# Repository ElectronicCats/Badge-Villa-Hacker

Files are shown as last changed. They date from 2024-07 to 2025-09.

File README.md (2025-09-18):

# La Villa Hacker 2025 Badge

## Technology

- CH32V003
- NRF24L01
- Display OLED
- 2x AAA Battery Holder
- Shitty Addon Connector

## Getting Started

Your badge comes with a pre-installed firmware, but in case you need to reprogram it, you can use the binaries from the release section.

If you want to build your own firmware, check out the [README](firmware/README.md) in the firmware folder.

## Gratitude
Do you want to say thank you? Tag these companies on social networks and show them your badge, thanks to them it is possible

- [Electronic Cats](https://electroniccats.com/)

## License

Electronic Cats invests time and resources providing this open source design, please support Electronic Cats and open-source hardware by purchasing products from Electronic Cats!

Designed by Electronic Cats.

Hardware released under an CERN Open Hardware Licence v1.2. See the LICENSE_HARDWARE file for more information.

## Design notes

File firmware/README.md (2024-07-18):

## Characteristics

* Microcontroller Puya PY32F002A    
  * PY32F002Ax5(20KB Flash/3KB RAM) SPI, USART, I2C, ADC.

## License
<a>
  
</a>

Designed by Electronic Cats for HackGDL

Electronic Cats invests time and resources in providing this open-source design. Please support Electronic Cats and open-source hardware by purchasing products from Electronic Cats!

Hardware released under ...

# PY32F0 SDK reference for Windows

[How to install the SDK for windows](https://github.com/ElectronicCats/puya-projects)

* Puya PY32F0 seriees template project for GNU Arm Embedded Toolchain
* Supported programmers: J-Link
* Supported IDE: VSCode

# File Structure

```
├── Build                       # Build results
├── Docs                        # Datesheets and User Manuals
├── Examples
│   ├── FreeRTOS                # FreeRTOS examples
│   ├── HAL                     # HAL library examples
│   └── LL                      # LL(Low Layer) library examples
├── Libraries
│   ├── BSP                     # SysTick delay and printf for debug
│   ├── BSP_LL                  # SysTick delay and printf for debug
│   ├── CMSIS
│   ├── FreeRTOS                # FreeRTOS library
│   ├── LDScripts               # LD files
│   ├── PY32F0xx_HAL_Driver     # MCU peripheral driver
│   └── PY32F0xx_LL_Driver      # MCU low layer peripheral driver
├── Makefile                    # Make config
├── Misc
│   ├── Flash
│   │   ├── JLinkDevices        # JLink flash loaders
│   │   └── Sources             # Flash algorithm source code
│   ├── Puya.PY32F0xx_DFP.x.pack # DFP pack file for PyOCD
│   └── SVD                     # SVD files
├── README.md
├── rules.mk                    # Pre-defined rules include in Makefile 
└── User                        # User application code
```

# Requirements

* Programmer
  * J-Link: J-Link OB programmer: https://linhkienthuduc.com/jlink-ob-072-mach-nap-cho-arm-cortex-m
* SEGGER J-Link Software and Documentation pack [https://www.segger.com/downloads/jlink/](https://www.segger.com/downloads/jlink/)
* GNU Arm Embedded Toolchain
* Make 

# Try Other Examples

[Forked Repository](https://github.com/IOsetting/py32f0-template)
More examples can be found in *Examples* folder of the forked repository, copy and replace the files under *User* folder of this repository to try different examples.

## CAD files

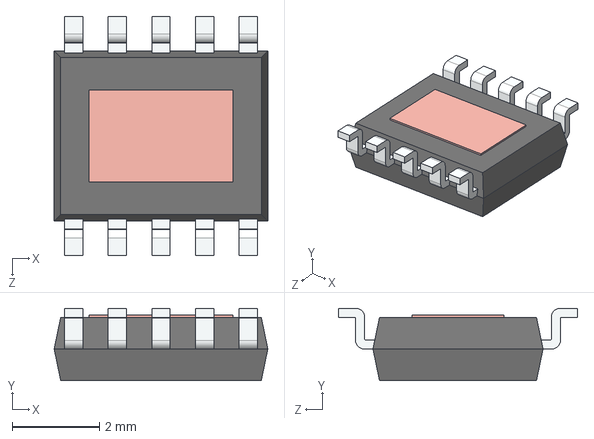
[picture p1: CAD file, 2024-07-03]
hardware/3d/ESOP-10.STEP
4.90 x 1.66 x 5.48 mm

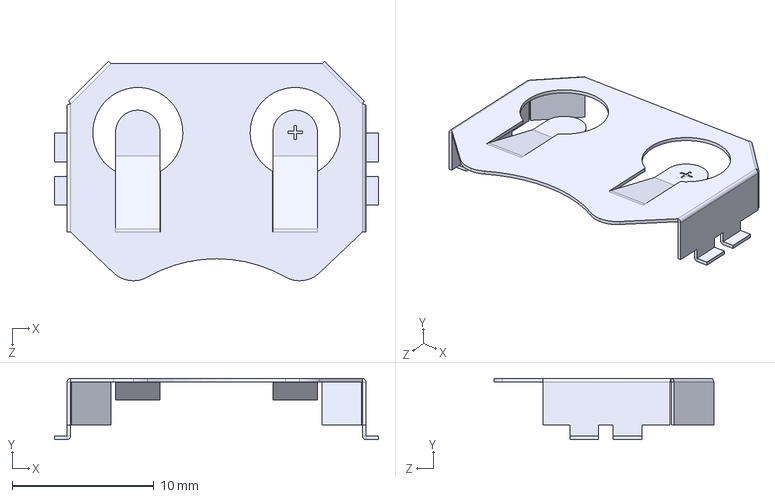
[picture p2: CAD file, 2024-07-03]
hardware/3d/BAT-HLD-001--3DModel-STEP-56544.STEP
22.9 x 4.32 x 15.5 mm

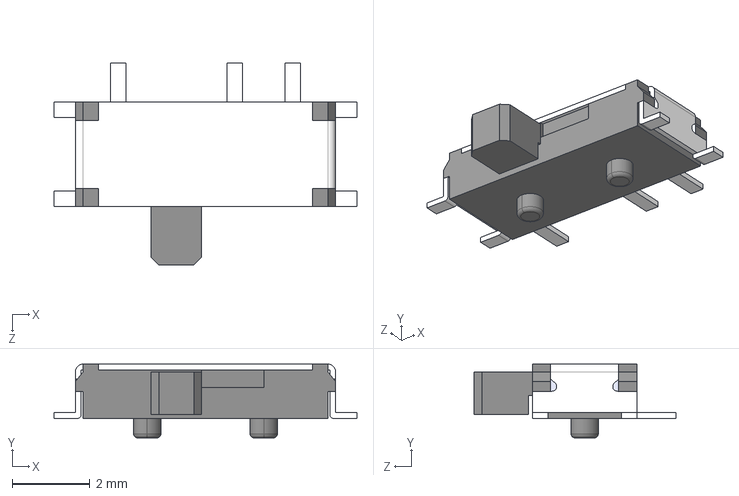
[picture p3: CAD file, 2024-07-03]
hardware/3d/MSK12C02.stp
7.80 x 1.90 x 5.20 mm

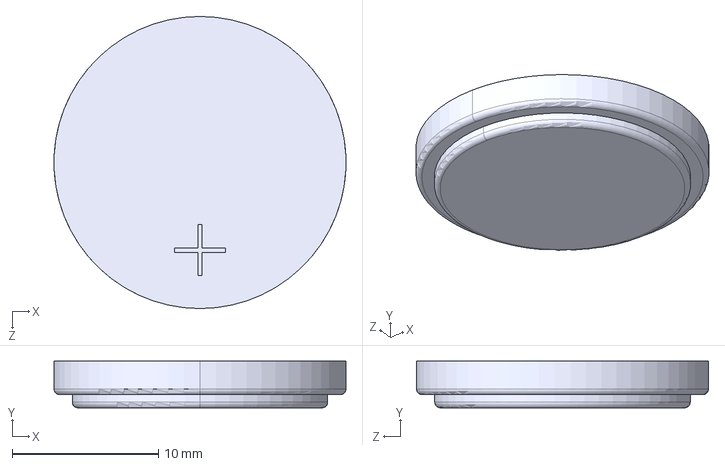
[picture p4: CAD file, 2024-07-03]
hardware/3d/CR2032--3DModel-STEP-56544.STEP
20.0 x 3.20 x 20.0 mm

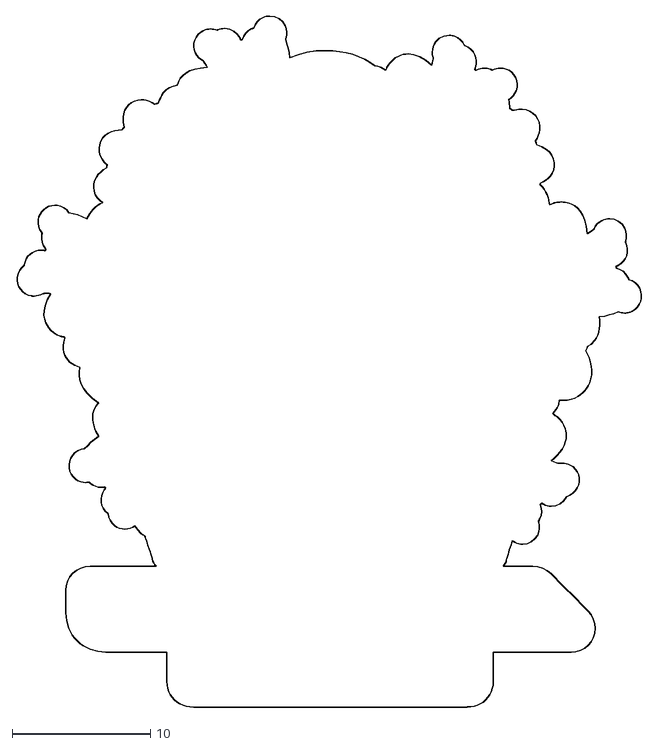
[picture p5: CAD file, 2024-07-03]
hardware/3d/Archivo SVG Badge La villa Hacker.dxf
45.4 x 50.0

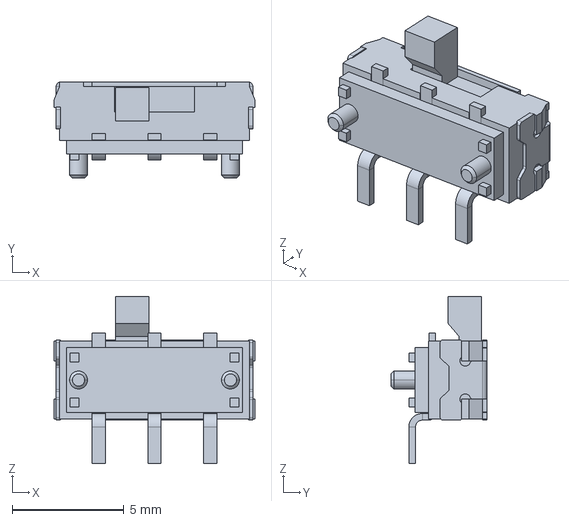
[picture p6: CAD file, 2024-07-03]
hardware/3d/JS102011SAQN--3DModel-Eagle-1.STEP
9.00 x 4.30 x 7.50 mm

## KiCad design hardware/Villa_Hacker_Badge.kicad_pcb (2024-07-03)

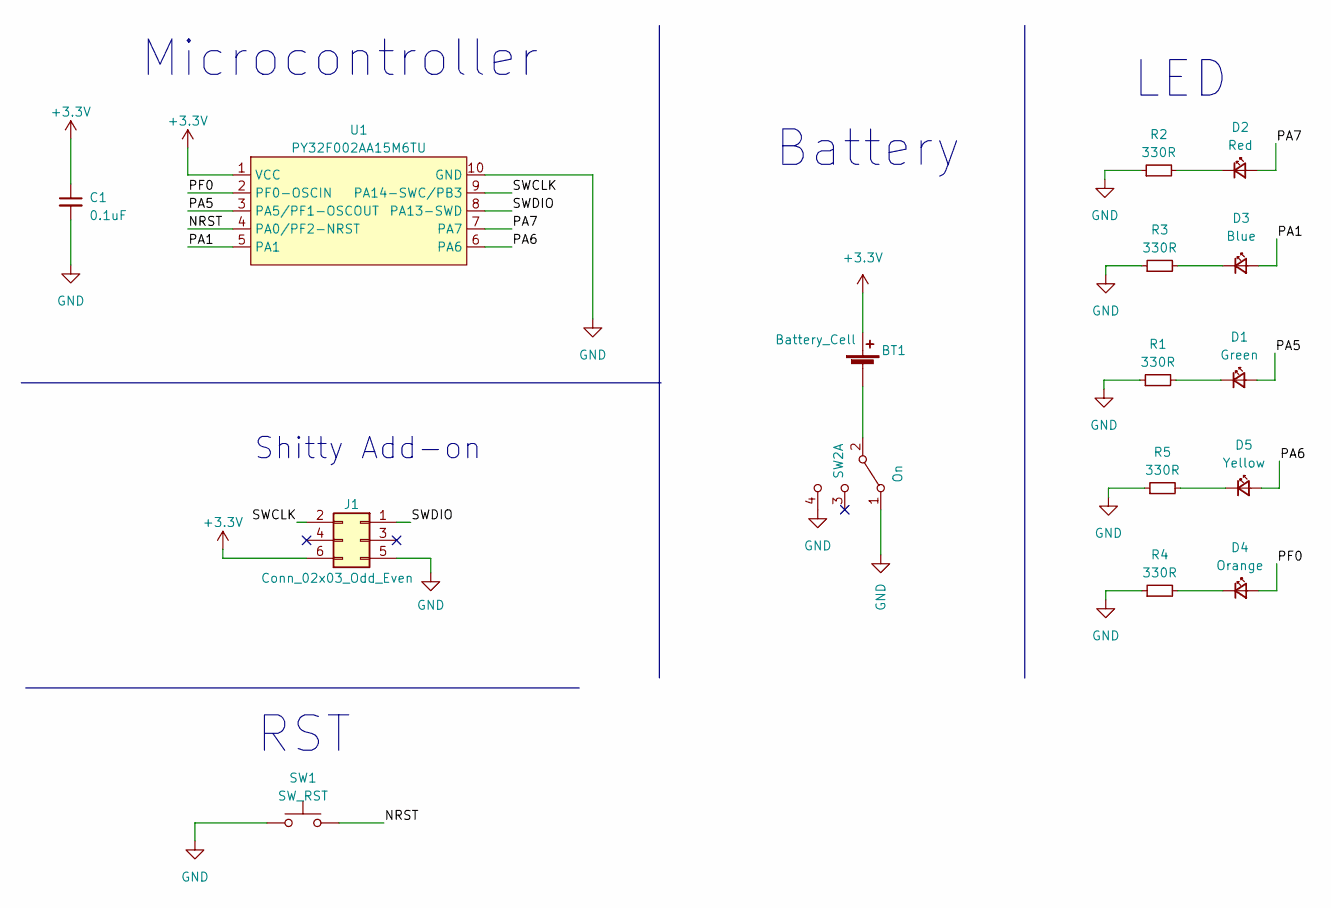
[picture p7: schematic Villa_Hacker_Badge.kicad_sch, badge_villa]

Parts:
BT1: Battery_Cell; BAT-HLD-001; LCSC# C964833
C1: 0.1uF; C_0805_2012Metric; LCSC# C235731
D1: Green; LED_0805_2012Metric; LCSC# C965815
D2: Red; LED_0805_2012Metric; LCSC# C965812
D3: Blue; LED_0805_2012Metric; LCSC# C205441
D4: Orange; LED_0805_2012Metric; LCSC# C434437
D5: Yellow; LED_0805_2012Metric; LCSC# C84261
J1: Conn_02x03_Odd_Even; PinHeader_2x03_P2.54mm_Vertical; LCSC# C706893
R1, R2, R3, R4, R5: 330R; R_0805_2012Metric; LCSC# C119075
SW1: SW_RST; SW_SPST_TL3342; LCSC# C318889
SW2: On; MSK12C02; LCSC# C431540
U1: PY32F002AA15M6TU; PY32F002AA15M; LCSC# C5292058

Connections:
+3.3V: BT1.2 (+), C1.1, J1.6, U1.1 (VCC)
/NRST: SW1.2, U1.4 (PA0/PF2-NRST)
/PA1: D3.2 (A), U1.5 (PA1)
/PA5: D1.2 (A), U1.3 (PA5/PF1-OSCOUT)
/PA6: D5.2 (A), U1.6 (PA6)
/PA7: D2.2 (A), U1.7 (PA7)
/PF0: D4.2 (A), U1.2 (PF0-OSCIN)
/SWCLK: J1.2, U1.9 (PA14-SWC/PB3)
/SWDIO: J1.1, U1.8 (PA13-SWD)
GND: C1.2, J1.5, R1.1, R2.1, R3.1, R4.1, R5.1, SW1.1, SW2.1 (A), SW2.4 (C), U1.10 (GND)
unnamed: BT1.1 (-), SW2.2 (B)
unnamed: D1.1 (K), R1.2
unnamed: D2.1 (K), R2.2
unnamed: D3.1 (K), R3.2
unnamed: D4.1 (K), R4.2
unnamed: D5.1 (K), R5.2

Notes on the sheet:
Shitty Add-on
Battery
Microcontroller
LED
RST

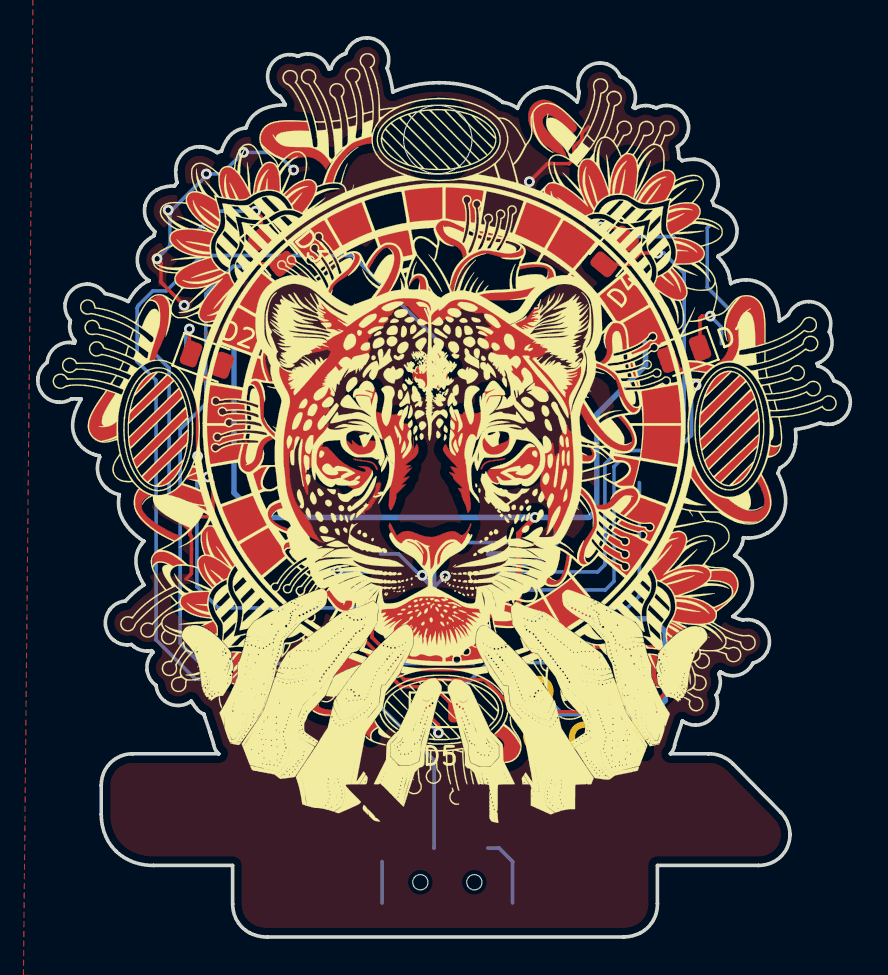
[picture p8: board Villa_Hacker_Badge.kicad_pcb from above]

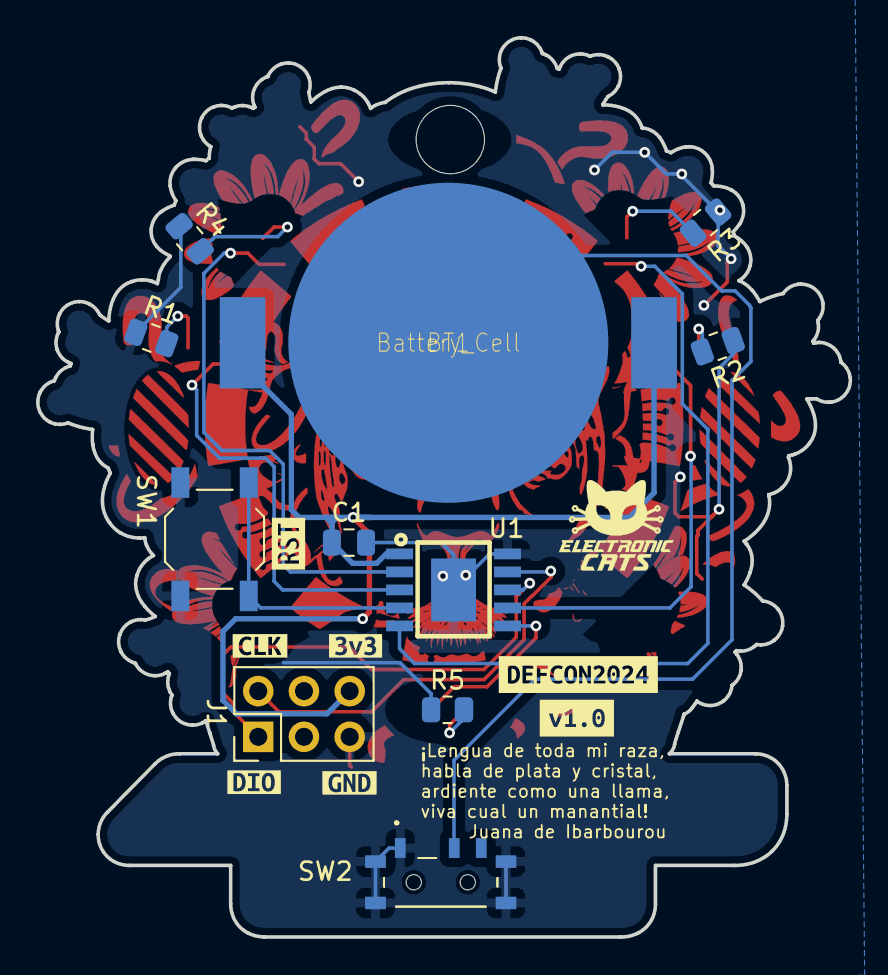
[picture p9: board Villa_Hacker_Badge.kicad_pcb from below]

Board: 2 copper layers, 45.1 x 50.0 mm, 24 parts (18 on the bottom side), 16 nets.

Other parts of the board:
Ref**: Val**; Archivo SVG Badge La villa Hacker
kibuzzard-6685D235: G***; kibuzzard-6685D235
kibuzzard-66857BF8: G***; kibuzzard-66857BF8
kibuzzard-66857C28: G***; kibuzzard-66857C28
kibuzzard-668588B5: G***; kibuzzard-668588B5
kibuzzard-6685884A: G***; kibuzzard-6685884A
kibuzzard-66858654: G***; kibuzzard-66858654
kibuzzard-66858661: G***; kibuzzard-66858661

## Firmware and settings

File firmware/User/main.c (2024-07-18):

/**
 ******************************************************************************
 * @file    main.c
 * @author  MCU Application Team
 * @brief   Main program body
 ******************************************************************************
 * @attention
 *
 * <h2><center>&copy; Copyright (c) Puya Semiconductor Co.
 * All rights reserved.</center></h2>
 *
 * <h2><center>&copy; Copyright (c) 2016 STMicroelectronics.
 * All rights reserved.</center></h2>
 *
 * This software component is licensed by ST under BSD 3-Clause license,
 * the "License"; You may not use this file except in compliance with the
 * License. You may obtain a copy of the License at:
 *                        opensource.org/licenses/BSD-3-Clause
 *
 * J-Link Connections: https://private-user-images.githubusercontent.com/44976441/277049150-2c44cddc-163c-4924-840f-2b99760bbca3.png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
 * PUYA instructions: https://github.com/ElectronicCats/puya-projects
 *
 ******************************************************************************
 */

/* Includes ------------------------------------------------------------------*/
#include "py32f0xx_bsp_printf.h"
#include <stdint.h>

/* Private define ------------------------------------------------------------*/
/* Private variables ---------------------------------------------------------*/
/* Private user code ---------------------------------------------------------*/
/* Private macro -------------------------------------------------------------*/
/* Private function prototypes -----------------------------------------------*/
static void APP_LedConfig(void);
uint16_t delay1 = 2000, delay3 = 3000, interimPeriod = 100;
uint8_t delay = 200, delay2 = 250, delay4 = 50, delay5 = 500;
uint8_t times = 0, init = 0;
uint8_t sequenceNumber = 1, timesSecretCode = 2, bitNumber = 0;

uint32_t ports[] = {GPIOA, GPIOA, GPIOF, GPIOA, GPIOA};
uint8_t pins[] = {0x0080, 0x0002, 0x0001, 0x0020, 0x0040}; 

uint8_t message[] = {"LATINO"};

void HEX2NIBBLE()
{
  uint8_t nibble1, nibble2;
  for (uint8_t i = 0; i < sizeof(message) - 1; i++)
  {
    nibble1 = message[i] & 0x0F;
    nibble2 = message[i] >> 4;
    bitNumber += 1;
    blinkBitNumber();
    setBits(nibble1);
    setBits(nibble2);
    ledsOff();
  }
}

void setBits(uint8_t nibble)
{
  uint8_t nibbleAux = nibble;
  for (uint8_t i = 0; i < 4; i++)
  {
    if (nibbleAux & 0x01) // LED ON
    {
      HAL_GPIO_OnPin(ports[i], pins[i]);
    }
    else
    {
      HAL_GPIO_OffPin(ports[i], pins[i]);
    }
    nibbleAux = nibble >> i + 1;
  }
  HAL_Delay(750);
}

void blinkBitNumber()
{
  for (uint8_t i = 0; i < 2; i++)
  {
    HAL_GPIO_OnPin(GPIOA, GPIO_PIN_6);
    HAL_Delay(delay);
    HAL_GPIO_OffPin(GPIOA, GPIO_PIN_6);
    HAL_Delay(delay);
  }
}

void ledsOff()
{
  HAL_GPIO_OffPin(GPIOF, GPIO_PIN_0);
  HAL_GPIO_OffPin(GPIOA, GPIO_PIN_1);
  HAL_GPIO_OffPin(GPIOA, GPIO_PIN_5);
  HAL_GPIO_OffPin(GPIOA, GPIO_PIN_6);
  HAL_GPIO_OffPin(GPIOA, GPIO_PIN_7);
}

// Sequence 1
void allblinkSequence()
{
  HAL_GPIO_OnPin(GPIOA, GPIO_PIN_5); 
  HAL_GPIO_OnPin(GPIOF, GPIO_PIN_0);
  HAL_GPIO_OnPin(GPIOA, GPIO_PIN_7); 
  HAL_GPIO_OnPin(GPIOA, GPIO_PIN_6);
  HAL_GPIO_OnPin(GPIOA, GPIO_PIN_1);
  HAL_Delay(delay3);
  HAL_GPIO_OffPin(GPIOA, GPIO_PIN_6); 
  HAL_GPIO_OffPin(GPIOA, GPIO_PIN_5);
  HAL_GPIO_OffPin(GPIOF, GPIO_PIN_0); 
  HAL_GPIO_OffPin(GPIOA, GPIO_PIN_7);
  HAL_GPIO_OffPin(GPIOA, GPIO_PIN_1);
  HAL_Delay(delay);

  HAL_GPIO_OnPin(GPIOA, GPIO_PIN_5); 
  HAL_GPIO_OnPin(GPIOF, GPIO_PIN_0);
  HAL_GPIO_OnPin(GPIOA, GPIO_PIN_7); 
  HAL_GPIO_OnPin(GPIOA, GPIO_PIN_6);
  HAL_GPIO_OnPin(GPIOA, GPIO_PIN_1);
  HAL_Delay(delay);
  HAL_GPIO_OffPin(GPIOA, GPIO_PIN_6); 
  HAL_GPIO_OffPin(GPIOA, GPIO_PIN_5);
  HAL_GPIO_OffPin(GPIOF, GPIO_PIN_0); 
  HAL_GPIO_OffPin(GPIOA, GPIO_PIN_7);
  HAL_GPIO_OffPin(GPIOA, GPIO_PIN_1);
  HAL_Delay(delay);

  HAL_GPIO_OnPin(GPIOA, GPIO_PIN_5); 
  HAL_GPIO_OnPin(GPIOF, GPIO_PIN_0);
  HAL_GPIO_OnPin(GPIOA, GPIO_PIN_7); 
  HAL_GPIO_OnPin(GPIOA, GPIO_PIN_6);
  HAL_GPIO_OnPin(GPIOA, GPIO_PIN_1);
  HAL_Delay(delay);
  HAL_GPIO_OffPin(GPIOA, GPIO_PIN_6); 
  HAL_GPIO_OffPin(GPIOA, GPIO_PIN_5);
  HAL_GPIO_OffPin(GPIOF, GPIO_PIN_0); 
  HAL_GPIO_OffPin(GPIOA, GPIO_PIN_7);
  HAL_GPIO_OffPin(GPIOA, GPIO_PIN_1);
  HAL_Delay(delay);

  HAL_GPIO_OnPin(GPIOA, GPIO_PIN_5); 
  HAL_GPIO_OnPin(GPIOF, GPIO_PIN_0);
  HAL_GPIO_OnPin(GPIOA, GPIO_PIN_7); 
  HAL_GPIO_OnPin(GPIOA, GPIO_PIN_6);
  HAL_GPIO_OnPin(GPIOA, GPIO_PIN_1);
  HAL_Delay(delay);
  HAL_GPIO_OffPin(GPIOA, GPIO_PIN_6); 
  HAL_GPIO_OffPin(GPIOA, GPIO_PIN_5);
  HAL_GPIO_OffPin(GPIOF, GPIO_PIN_0); 
  HAL_GPIO_OffPin(GPIOA, GPIO_PIN_7);
  HAL_GPIO_OffPin(GPIOA, GPIO_PIN_1);
  HAL_Delay(delay);
}

// Sequence 2
void oneandoneSequence()
{
  HAL_GPIO_OnPin(GPIOA, GPIO_PIN_7);
  HAL_Delay(delay5);
  HAL_GPIO_OffPin(GPIOA, GPIO_PIN_7);
  HAL_GPIO_OnPin(GPIOA, GPIO_PIN_1);
  HAL_Delay(delay5);
  HAL_GPIO_OffPin(GPIOA, GPIO_PIN_1);
  HAL_Delay(delay5);
  HAL_GPIO_OnPin(GPIOF, GPIO_PIN_0);
  HAL_Delay(delay5);
  HAL_GPIO_OffPin(GPIOF, GPIO_PIN_0);
  HAL_GPIO_OnPin(GPIOA, GPIO_PIN_5); 
  HAL_Delay(delay5);
  HAL_GPIO_OffPin(GPIOA, GPIO_PIN_5);
  HAL_GPIO_OnPin(GPIOA, GPIO_PIN_6);
  HAL_Delay(delay5);
  HAL_GPIO_OffPin(GPIOA, GPIO_PIN_6);
}

// Sequence 3
void randomSequence()
{ 
  HAL_GPIO_OnPin(GPIOA, GPIO_PIN_7);
  HAL_GPIO_OnPin(GPIOF, GPIO_PIN_0);
  HAL_Delay(delay2);
  HAL_GPIO_OffPin(GPIOA, GPIO_PIN_7);
  HAL_GPIO_OffPin(GPIOF, GPIO_PIN_0);
  HAL_GPIO_OnPin(GPIOA, GPIO_PIN_5); 
  HAL_GPIO_OnPin(GPIOA, GPIO_PIN_1);
  HAL_Delay(delay2);
  HAL_GPIO_OffPin(GPIOA, GPIO_PIN_5); 
  HAL_GPIO_OffPin(GPIOA, GPIO_PIN_1);
  HAL_GPIO_OnPin(GPIOA, GPIO_PIN_6);
  HAL_Delay(delay2);
  HAL_GPIO_OffPin(GPIOA, GPIO_PIN_6);
  HAL_Delay(delay2);

  HAL_GPIO_OnPin(GPIOA, GPIO_PIN_6);
  HAL_GPIO_OnPin(GPIOA, GPIO_PIN_1);
  HAL_Delay(delay2);
  HAL_GPIO_OffPin(GPIOA, GPIO_PIN_1);
  HAL_GPIO_OnPin(GPIOF, GPIO_PIN_0);
  HAL_Delay(delay2);
  HAL_GPIO_OffPin(GPIOF, GPIO_PIN_0);
  HAL_GPIO_OffPin(GPIOA, GPIO_PIN_6);
  HAL_GPIO_OnPin(GPIOA, GPIO_PIN_7);
  HAL_GPIO_OnPin(GPIOA, GPIO_PIN_5); 
  HAL_Delay(delay2);
  HAL_GPIO_OffPin(GPIOA, GPIO_PIN_7);
  HAL_GPIO_OffPin(GPIOA, GPIO_PIN_5);
  HAL_Delay(delay2);

  HAL_GPIO_OnPin(GPIOA, GPIO_PIN_1);
  HAL_GPIO_OnPin(GPIOF, GPIO_PIN_0);
  HAL_Delay(delay2);
  HAL_GPIO_OnPin(GPIOA, GPIO_PIN_7);
  HAL_GPIO_OnPin(GPIOA, GPIO_PIN_5); 
  HAL_Delay(delay2);
  HAL_GPIO_OnPin(GPIOA, GPIO_PIN_6);
  HAL_Delay(delay2);
  HAL_GPIO_OffPin(GPIOA, GPIO_PIN_1);
  HAL_GPIO_OffPin(GPIOF, GPIO_PIN_0);
  HAL_Delay(delay2);
  HAL_GPIO_OffPin(GPIOA, GPIO_PIN_7);
  HAL_GPIO_OffPin(GPIOA, GPIO_PIN_5);
  HAL_Delay(delay2);
  HAL_GPIO_OffPin(GPIOA, GPIO_PIN_6);
}

// Sequence 4
void rouletteSequence()
{
  HAL_GPIO_OnPin(GPIOA, GPIO_PIN_7); 
  HAL_Delay(delay2);
  HAL_GPIO_OnPin(GPIOA, GPIO_PIN_1); 
  HAL_Delay(delay2);
  HAL_GPIO_OnPin(GPIOF, GPIO_PIN_0); 
  HAL_Delay(delay2);
  HAL_GPIO_OnPin(GPIOA, GPIO_PIN_5); 
  HAL_Delay(delay2);
  HAL_GPIO_OnPin(GPIOA, GPIO_PIN_6); 
  HAL_Delay(delay2);

  HAL_GPIO_OffPin(GPIOA, GPIO_PIN_7);
  HAL_Delay(delay2);
  HAL_GPIO_OffPin(GPIOA, GPIO_PIN_1);
  HAL_Delay(delay2);
  HAL_GPIO_OffPin(GPIOF, GPIO_PIN_0);
  HAL_Delay(delay2);
  HAL_GPIO_OffPin(GPIOA, GPIO_PIN_5);
  HAL_Delay(delay2);
  HAL_GPIO_OffPin(GPIOA, GPIO_PIN_6);
  HAL_Delay(delay2);
}

// Sequence 5
void doublerouletteSequence()
{
  HAL_GPIO_OnPin(GPIOA, GPIO_PIN_6); 
  HAL_GPIO_OnPin(GPIOA, GPIO_PIN_7); 
  HAL_Delay(delay2);
  HAL_GPIO_OffPin(GPIOA, GPIO_PIN_6); 
  HAL_GPIO_OnPin(GPIOA, GPIO_PIN_1); 
  HAL_Delay(delay2);
  HAL_GPIO_OffPin(GPIOA, GPIO_PIN_7);
  HAL_GPIO_OnPin(GPIOF, GPIO_PIN_0);
  HAL_Delay(delay2);
  HAL_GPIO_OffPin(GPIOA, GPIO_PIN_1);
  HAL_GPIO_OnPin(GPIOA, GPIO_PIN_5); 
  HAL_Delay(delay2);
  HAL_GPIO_OffPin(GPIOF, GPIO_PIN_0);
  HAL_GPIO_OnPin(GPIOA, GPIO_PIN_6); 
  HAL_Delay(delay2);
   

  HAL_GPIO_OffPin(GPIOA, GPIO_PIN_5); 
  HAL_GPIO_OnPin(GPIOA, GPIO_PIN_7); 
  HAL_Delay(delay2);
  HAL_GPIO_OffPin(GPIOA, GPIO_PIN_6); 
  HAL_GPIO_OnPin(GPIOA, GPIO_PIN_1); 
  HAL_Delay(delay2);
  HAL_GPIO_OffPin(GPIOA, GPIO_PIN_7);
  HAL_GPIO_OnPin(GPIOF, GPIO_PIN_0);
  HAL_Delay(delay2);
  HAL_GPIO_OffPin(GPIOA, GPIO_PIN_1);
  HAL_GPIO_OnPin(GPIOA, GPIO_PIN_5); 
  HAL_Delay(delay2);
  HAL_GPIO_OffPin(GPIOF, GPIO_PIN_0);
  HAL_GPIO_OnPin(GPIOA, GPIO_PIN_6); 
  HAL_Delay(delay2);

  HAL_GPIO_OffPin(GPIOA, GPIO_PIN_5);
  HAL_GPIO_OnPin(GPIOA, GPIO_PIN_7); 
  HAL_Delay(delay2);
  HAL_GPIO_OffPin(GPIOA, GPIO_PIN_6); 
  HAL_GPIO_OnPin(GPIOA, GPIO_PIN_1); 
  HAL_Delay(delay2);
  HAL_GPIO_OffPin(GPIOA, GPIO_PIN_7);
  HAL_GPIO_OnPin(GPIOF, GPIO_PIN_0);
  HAL_Delay(delay2);
  HAL_GPIO_OffPin(GPIOA, GPIO_PIN_1);
  HAL_GPIO_OnPin(GPIOA, GPIO_PIN_5); 
  HAL_Delay(delay2);
  HAL_GPIO_OffPin(GPIOF, GPIO_PIN_0);
  HAL_GPIO_OnPin(GPIOA, GPIO_PIN_6); 
  HAL_Delay(delay2);
  HAL_GPIO_OffPin(GPIOA, GPIO_PIN_5);
  HAL_GPIO_OffPin(GPIOA, GPIO_PIN_6); 
}

// Sequence 6
void fastrouletteSequence()
{
  HAL_GPIO_OnPin(GPIOA, GPIO_PIN_6); 
  HAL_Delay(delay4);
  HAL_GPIO_OffPin(GPIOA, GPIO_PIN_6);
  HAL_Delay(delay4);
  HAL_GPIO_OnPin(GPIOA, GPIO_PIN_7); 
  HAL_Delay(delay4);
  HAL_GPIO_OffPin(GPIOA, GPIO_PIN_7);
  HAL_Delay(delay4);
  HAL_GPIO_OnPin(GPIOA, GPIO_PIN_1); 
  HAL_Delay(delay4);
  HAL_GPIO_OffPin(GPIOA, GPIO_PIN_1);
  HAL_Delay(delay4);
  HAL_GPIO_OnPin(GPIOF, GPIO_PIN_0); 
  HAL_Delay(delay4);
  HAL_GPIO_OffPin(GPIOF, GPIO_PIN_0);
  HAL_Delay(delay4);
  HAL_GPIO_OnPin(GPIOA, GPIO_PIN_5); 
  HAL_Delay(delay4);
  HAL_GPIO_OffPin(GPIOA, GPIO_PIN_5);
  HAL_Delay(delay4);

  HAL_GPIO_OnPin(GPIOA, GPIO_PIN_6); 
  HAL_Delay(delay4);
  HAL_GPIO_OffPin(GPIOA, GPIO_PIN_6);
  HAL_Delay(delay4);
  HAL_GPIO_OnPin(GPIOA, GPIO_PIN_7); 
  HAL_Delay(delay4);
  HAL_GPIO_OffPin(GPIOA, GPIO_PIN_7);
  HAL_Delay(delay4);
  HAL_GPIO_OnPin(GPIOA, GPIO_PIN_1); 
  HAL_Delay(delay4);
  HAL_GPIO_OffPin(GPIOA, GPIO_PIN_1);
  HAL_Delay(delay4);
  HAL_GPIO_OnPin(GPIOF, GPIO_PIN_0); 
  HAL_Delay(delay4);
  HAL_GPIO_OffPin(GPIOF, GPIO_PIN_0);
  HAL_Delay(delay4);
  HAL_GPIO_OnPin(GPIOA, GPIO_PIN_5); 
  HAL_Delay(delay4);
  HAL_GPIO_OffPin(GPIOA, GPIO_PIN_5);
  HAL_Delay(delay4);

  HAL_GPIO_OnPin(GPIOA, GPIO_PIN_6); 
  HAL_Delay(delay4);
  HAL_GPIO_OffPin(GPIOA, GPIO_PIN_6);
  HAL_Delay(delay4);
  HAL_GPIO_OnPin(GPIOA, GPIO_PIN_7); 
  HAL_Delay(delay4);
  HAL_GPIO_OffPin(GPIOA, GPIO_PIN_7);
  HAL_Delay(delay4);
  HAL_GPIO_OnPin(GPIOA, GPIO_PIN_1); 
  HAL_Delay(delay4);
  HAL_GPIO_OffPin(GPIOA, GPIO_PIN_1);
  HAL_Delay(delay4);
  HAL_GPIO_OnPin(GPIOF, GPIO_PIN_0); 
  HAL_Delay(delay4);
  HAL_GPIO_OffPin(GPIOF, GPIO_PIN_0);
  HAL_Delay(delay4);
  HAL_GPIO_OnPin(GPIOA, GPIO_PIN_5); 
  HAL_Delay(delay4);
  HAL_GPIO_OffPin(GPIOA, GPIO_PIN_5);
  HAL_Delay(delay4);

  HAL_GPIO_OnPin(GPIOA, GPIO_PIN_6); 
  HAL_Delay(delay4);
  HAL_GPIO_OffPin(GPIOA, GPIO_PIN_6);
  HAL_Delay(delay4);
  HAL_GPIO_OnPin(GPIOA, GPIO_PIN_7); 
  HAL_Delay(delay4);
  HAL_GPIO_OffPin(GPIOA, GPIO_PIN_7);
  HAL_Delay(delay4);
  HAL_GPIO_OnPin(GPIOA, GPIO_PIN_1); 
  HAL_Delay(delay4);
  HAL_GPIO_OffPin(GPIOA, GPIO_PIN_1);
  HAL_Delay(delay4);
  HAL_GPIO_OnPin(GPIOF, GPIO_PIN_0); 
  HAL_Delay(delay4);
  HAL_GPIO_OffPin(GPIOF, GPIO_PIN_0);
  HAL_Delay(delay4);
  HAL_GPIO_OnPin(GPIOA, GPIO_PIN_5); 
  HAL_Delay(delay4);
  HAL_GPIO_OffPin(GPIOA, GPIO_PIN_5);
  HAL_Delay(delay4);

  HAL_GPIO_OnPin(GPIOA, GPIO_PIN_6); 
  HAL_Delay(delay4);
  HAL_GPIO_OffPin(GPIOA, GPIO_PIN_6);
  HAL_Delay(delay4);
  HAL_GPIO_OnPin(GPIOA, GPIO_PIN_7); 
  HAL_Delay(delay4);
  HAL_GPIO_OffPin(GPIOA, GPIO_PIN_7);
  HAL_Delay(delay4);
  HAL_GPIO_OnPin(GPIOA, GPIO_PIN_1); 
  HAL_Delay(delay4);
  HAL_GPIO_OffPin(GPIOA, GPIO_PIN_1);
  HAL_Delay(delay4);
  HAL_GPIO_OnPin(GPIOF, GPIO_PIN_0); 
  HAL_Delay(delay4);
  HAL_GPIO_OffPin(GPIOF, GPIO_PIN_0);
  HAL_Delay(delay4);
  HAL_GPIO_OnPin(GPIOA, GPIO_PIN_5); 
  HAL_Delay(delay4);
  HAL_GPIO_OffPin(GPIOA, GPIO_PIN_5);
  HAL_Delay(delay4);

  HAL_GPIO_OnPin(GPIOA, GPIO_PIN_6); 
  HAL_Delay(delay4);
  HAL_GPIO_OffPin(GPIOA, GPIO_PIN_6);
  HAL_Delay(delay4);
  HAL_GPIO_OnPin(GPIOA, GPIO_PIN_7); 
  HAL_Delay(delay4);
  HAL_GPIO_OffPin(GPIOA, GPIO_PIN_7);
  HAL_Delay(delay4);
  HAL_GPIO_OnPin(GPIOA, GPIO_PIN_1); 
  HAL_Delay(delay4);
  HAL_GPIO_OffPin(GPIOA, GPIO_PIN_1);
  HAL_Delay(delay4);
  HAL_GPIO_OnPin(GPIOF, GPIO_PIN_0); 
  HAL_Delay(delay4);
  HAL_GPIO_OffPin(GPIOF, GPIO_PIN_0);
  HAL_Delay(delay4);
  HAL_GPIO_OnPin(GPIOA, GPIO_PIN_5); 
  HAL_Delay(delay4);
  HAL_GPIO_OffPin(GPIOA, GPIO_PIN_5);
  HAL_Delay(delay4);

  HAL_GPIO_OnPin(GPIOA, GPIO_PIN_6); 
  HAL_Delay(delay4);
  HAL_GPIO_OffPin(GPIOA, GPIO_PIN_6);
  HAL_Delay(delay4);
  HAL_GPIO_OnPin(GPIOA, GPIO_PIN_7); 
  HAL_Delay(delay4);
  HAL_GPIO_OffPin(GPIOA, GPIO_PIN_7);
  HAL_Delay(delay4);
  HAL_GPIO_OnPin(GPIOA, GPIO_PIN_1); 
  HAL_Delay(delay4);
  HAL_GPIO_OffPin(GPIOA, GPIO_PIN_1);
  HAL_Delay(delay4);
  HAL_GPIO_OnPin(GPIOF, GPIO_PIN_0); 
  HAL_Delay(delay4);
  HAL_GPIO_OffPin(GPIOF, GPIO_PIN_0);
  HAL_Delay(delay4);
  HAL_GPIO_OnPin(GPIOA, GPIO_PIN_5); 
  HAL_Delay(delay4);
  HAL_GPIO_OffPin(GPIOA, GPIO_PIN_5);
  HAL_Delay(delay4);

  HAL_GPIO_OnPin(GPIOA, GPIO_PIN_6); 
  HAL_Delay(delay4);
  HAL_GPIO_OffPin(GPIOA, GPIO_PIN_6);
  HAL_Delay(delay4);
  HAL_GPIO_OnPin(GPIOA, GPIO_PIN_7); 
  HAL_Delay(delay4);
  HAL_GPIO_OffPin(GPIOA, GPIO_PIN_7);
  HAL_Delay(delay4);
  HAL_GPIO_OnPin(GPIOA, GPIO_PIN_1); 
  HAL_Delay(delay4);
  HAL_GPIO_OffPin(GPIOA, GPIO_PIN_1);
  HAL_Delay(delay4);
  HAL_GPIO_OnPin(GPIOF, GPIO_PIN_0); 
  HAL_Delay(delay4);
  HAL_GPIO_OffPin(GPIOF, GPIO_PIN_0);
  HAL_Delay(delay4);
  HAL_GPIO_OnPin(GPIOA, GPIO_PIN_5); 
  HAL_Delay(delay4);
  HAL_GPIO_OffPin(GPIOA, GPIO_PIN_5);
  HAL_Delay(delay4);
}

//Cases
void sequences(int sequence)
{
  switch (sequence)
  {
  case 1:
    allblinkSequence();
    break;
  case 2:
    oneandoneSequence();
    break;
  case 3:
    randomSequence();
    break;
  case 4:
    rouletteSequence();
    break;
  case 5:
    doublerouletteSequence();
    break;
  case 6:
    fastrouletteSequence();
    break;
  default:
    HAL_Delay(1000);
    break;
  }
}

int main(void)
{
  HAL_Init();

  APP_LedConfig();

  BSP_USART_Config();


  while (1)
  {
    for (uint8_t c = 1; c < 7; c++)
    {
      sequences(c);
    }

    for (uint8_t c2 = 0; c2 < timesSecretCode; c2++)
    {
      ledsOff();
      HAL_Delay(interimPeriod);
      HEX2NIBBLE();
      HAL_Delay(interimPeriod);
    }
  }
}

static void APP_LedConfig(void)
{
  GPIO_InitTypeDef GPIO_InitStruct;

  __HAL_RCC_GPIOA_CLK_ENABLE();

  GPIO_InitStruct.Pin = GPIO_PIN_1;
  GPIO_InitStruct.Mode = GPIO_MODE_OUTPUT_PP;
  GPIO_InitStruct.Pull = GPIO_PULLUP;
  GPIO_InitStruct.Speed = GPIO_SPEED_FREQ_HIGH;
  HAL_GPIO_Init(GPIOA, &GPIO_InitStruct);

  __HAL_RCC_GPIOA_CLK_ENABLE();

  GPIO_InitStruct.Pin = GPIO_PIN_6;
  GPIO_InitStruct.Mode = GPIO_MODE_OUTPUT_PP;
  GPIO_InitStruct.Pull = GPIO_PULLUP;
  GPIO_InitStruct.Speed = GPIO_SPEED_FREQ_HIGH;
  HAL_GPIO_Init(GPIOA, &GPIO_InitStruct);

  __HAL_RCC_GPIOA_CLK_ENABLE();

  GPIO_InitStruct.Pin = GPIO_PIN_7;
  GPIO_InitStruct.Mode = GPIO_MODE_OUTPUT_PP;
  GPIO_InitStruct.Pull = GPIO_PULLUP;
  GPIO_InitStruct.Speed = GPIO_SPEED_FREQ_HIGH;

  HAL_GPIO_Init(GPIOA, &GPIO_InitStruct);

  __HAL_RCC_GPIOA_CLK_ENABLE();

  GPIO_InitStruct.Pin = GPIO_PIN_5;
  GPIO_InitStruct.Mode = GPIO_MODE_OUTPUT_PP;
  GPIO_InitStruct.Pull = GPIO_PULLUP;
  GPIO_InitStruct.Speed = GPIO_SPEED_FREQ_HIGH;

  HAL_GPIO_Init(GPIOA, &GPIO_InitStruct);

  __HAL_RCC_GPIOF_CLK_ENABLE();

  GPIO_InitStruct.Pin = GPIO_PIN_0;
  GPIO_InitStruct.Mode = GPIO_MODE_OUTPUT_PP;
  GPIO_InitStruct.Pull = GPIO_PULLUP;
  GPIO_InitStruct.Speed = GPIO_SPEED_FREQ_HIGH;

  HAL_GPIO_Init(GPIOF, &GPIO_InitStruct);
}

void APP_ErrorHandler(void)
{
  while (1)
    ;
}

#ifdef USE_FULL_ASSERT

void assert_failed(uint8_t *file, uint32_t line)
{
  while (1)
  {
  }
}
#endif /* USE_FULL_ASSERT */

/************************ (C) COPYRIGHT Puya *****END OF FILE******************/

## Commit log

2024-07-03 feat(hw): add labels and logos
    [Villa_Hacker_Badge.kicad_pcb]
2024-07-03 fix (hw): update #LCSC orange LED
    [Villa_Hacker_Badge.kicad_sch]
2024-07-03 fix(hw): logo EC
    [Villa_Hacker_Badge.kicad_pcb]
